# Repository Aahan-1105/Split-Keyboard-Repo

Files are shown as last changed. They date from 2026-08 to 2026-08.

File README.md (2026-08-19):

# Venturi - 48 Key Split Keyboard
*Code name: Model 901*

My first PCBs, first personal electronics project, and much more. This has been a lot of firsts so please excuse mistakes. Key inspiration is also mentioned below.

Steal from the best, invent the rest

## FIRMWARE in THIS REPO

## Overview
The Venturi (aka model 901, venturi48) is a 48-key split, ergonomic keyboard. I can use lots of descriptors, but you can find that in the features section. 

## Contents
- All the KiCad files, including schematics and PCB
- All CAD Files including an assembly including all the components on the left side and cases for both
- ZMK firmware for Venturi
- Production files as used for production

## Images

### CAD Render
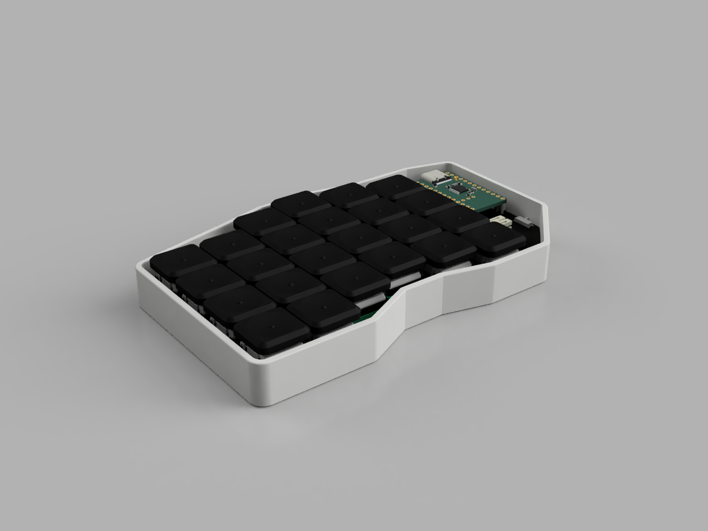
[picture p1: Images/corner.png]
Corner Render


### Schematic (Left)
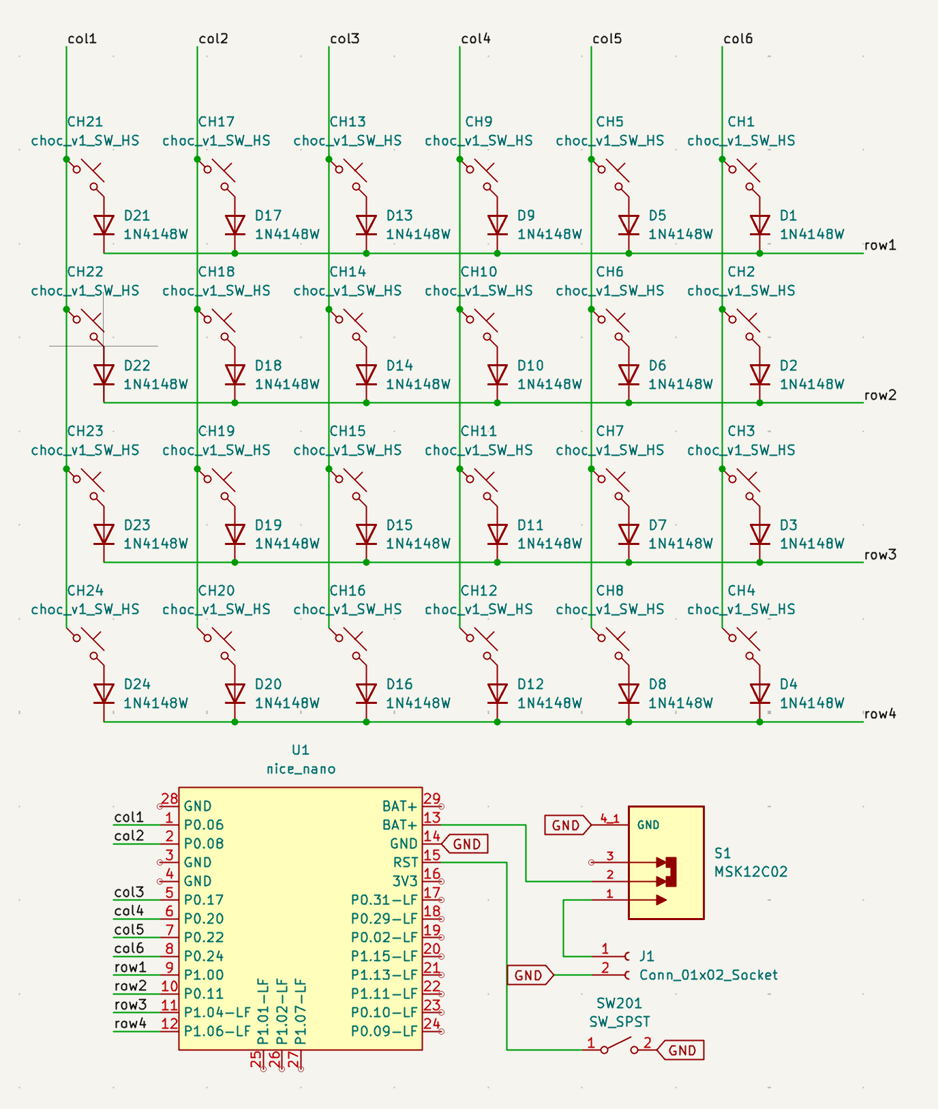
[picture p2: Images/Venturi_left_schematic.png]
Left Schematic


### PCB (Panelized)
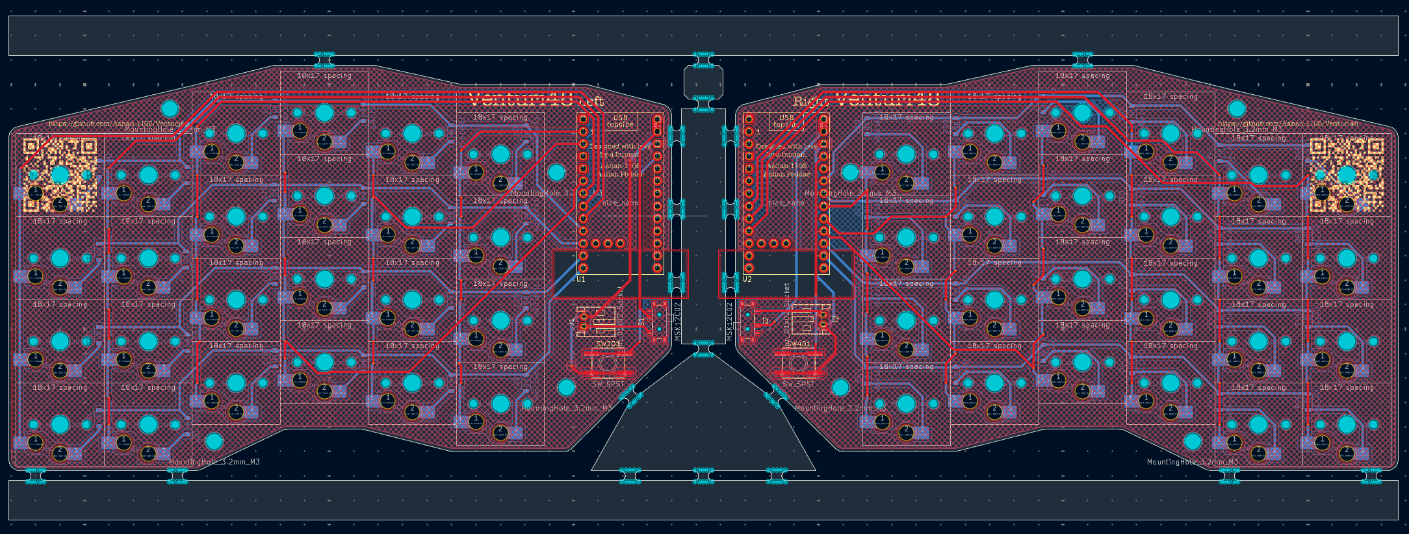
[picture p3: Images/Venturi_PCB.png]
Panelized PCB


## To-Do
- Triple-check that PCBs are good and needed components are accounted for
- PURCHASE
- Assemble and test!

## Features
- **48 Keys**  - All laptop keys within 2 layers, with additional layers for extra functionality. 
- **Wireless** - One less cable to worry about! 2x 110 maH LiPO Batteries, 2+ week battery life (estimated). Seamless multi-device operation.
- **Column Stagger** - Some mild colstag makes it more comfy to type on by better suting the different finger lengths
- **Keyboard Continuity** - Closer layout to a Macbook or general keyboard than most ergo KBs, so that you're not mad at all other keyboards while using this
- **Low Profile**  - Thinner = Better? More portable and less of an upward angle on the wrists, no need for a wrist rest 
- **Portable** - Easy on the go typing via a 3d print to easily carry it without risking damage in a backpack
- **Hot-Swappable** - Changed your mind on those clicky switches? Or maybe you're looking for a change of pace? The Venturi has you covered with hotswap switches!
- **Magsafe** - Not to wirelessly charge or to attach to the back of your phone, but for convenient tenting or to check if that coin is magnetic or not (it wasn't)

## BOM (For Hackclub Stardance Purposes)
|Purchase Status|Part |Qty|Price/per (CAD)|Total |Link |Shipping/Tax|Notes |
|---|---|---|---|---|---|---|---|
| |NRF52840 Dev Board |2  |$3.95 |$7.90 |https://a.aliexpress.com/_mrUhUVZ| |MC |
| |MSK12C02 (20 pack) |1  |$3.85 |$3.85 |https://a.aliexpress.com/_mLPJnJ1| |Power Switch |
| |JST PH 2.0 Bent Plug (100 pack)|1  |$2.61 |$2.61 |https://a.aliexpress.com/_m0dvH4j| |Battery Connector |
| |1N4148W Diode (100 pack) |1  |$2.07 |$2.07 |https://a.aliexpress.com/_mNCQ5SX| |Diodes |
| |Choc Hotswap Socket (70 pack)  |1  |$10.48 |$10.48|https://a.aliexpress.com/_mq1DDpN| |Hotswap Socket |
| |2.54mm socket (10 pack) |1  |$2.64 |$2.64 |https://a.aliexpress.com/_mtOu6HZ| |Sockets for MC |
| |KailH Choc Pro Red |1  |$32.26 |$32.26|https://a.aliexpress.com/_mKtAtkx| |Switch |
| |301230 Battery JST |2  |$5.19 |$10.38|https://a.aliexpress.com/_mt5WUH1|6.18 |Battery |
| |JLCPCB PCB |1  |$17.73 |$17.73| |12.37 |PCB (no link available)  |
| |FNIRSI HS-02A Basic |1  |$39.44 |$39.44|https://a.aliexpress.com/_mKQRvMj| |Soldering Iron |
| |Magsafe Ring (6) |1  |$7.51 |$7.51 |https://a.aliexpress.com/_mtm6duj| |Magsafe Ring for Mounting|
| |20g Lead-free solder |1  |$5.29 |$5.29 |https://a.aliexpress.com/_mKjygpD| |Soldering |
| |Flux Pen 10mL |1  |$4.98 |$4.98 |https://a.aliexpress.com/_mKjygpD| |Flux for soldering |
| | | | |$0.00 | | | |
| | | | |$0.00 | | | |
| |TOTAL (CAD) | |$165.69 |$0.00 | | | |
| |TOTAL (USD) | |$119.30 |$0.00 | | | |

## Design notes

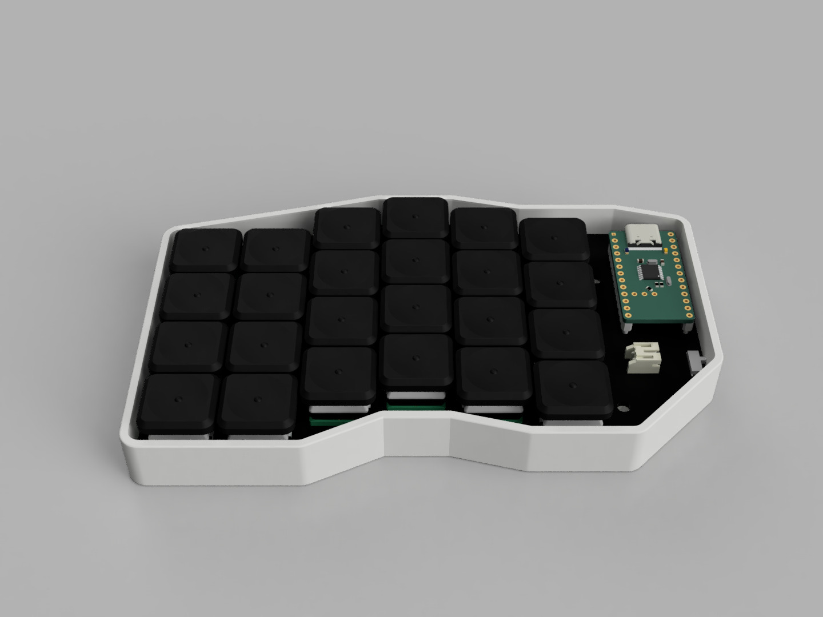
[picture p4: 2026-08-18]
Images/front.png

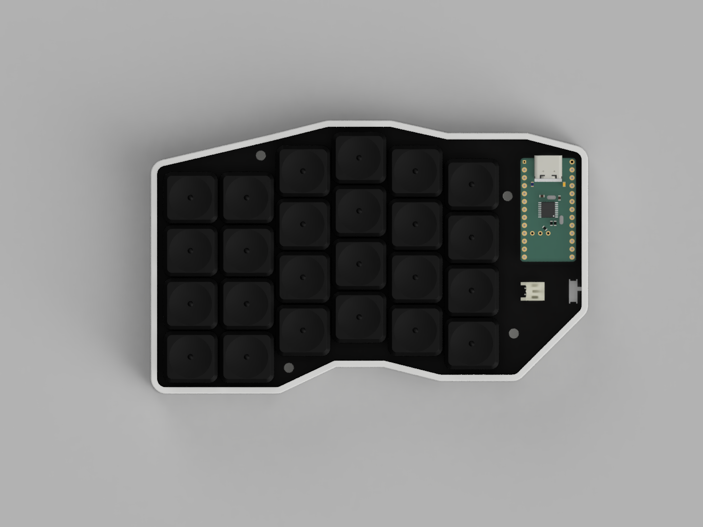
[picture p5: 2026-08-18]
Images/top.png

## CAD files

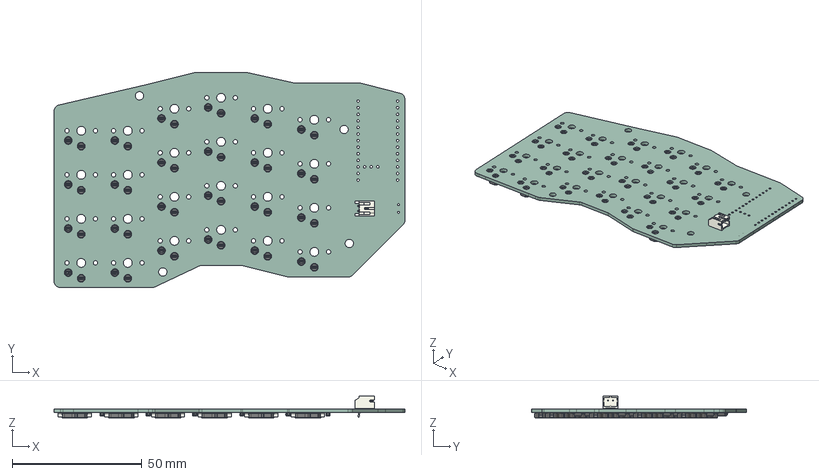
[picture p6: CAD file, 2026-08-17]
CAD/External STEP Files/Left_Half.step
135.5 x 83.0 x 8.49 mm
JST_S2B_PH_K
pin x 48
socket x 24
D_SOD-123 x 24
Left_Half_PCB-unsaved-export-nb2ApT_PCB

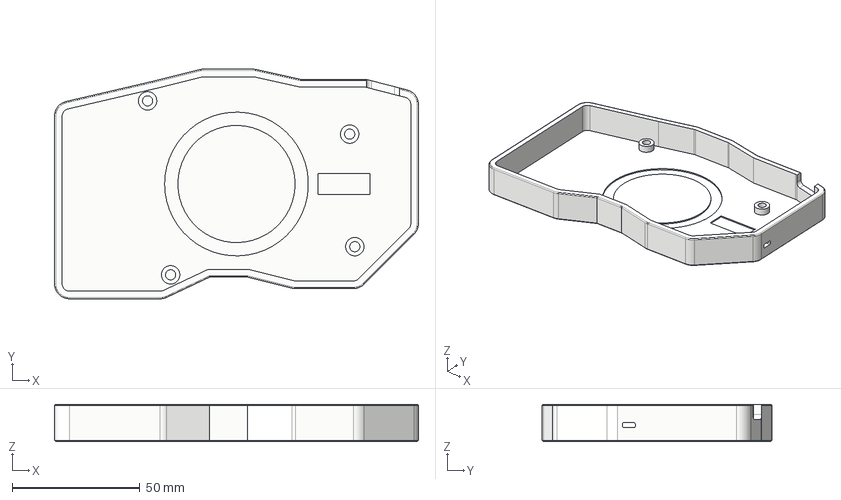
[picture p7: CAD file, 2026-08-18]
CAD/Venturi Left Half Case.step
142.3 x 89.8 x 14.6 mm

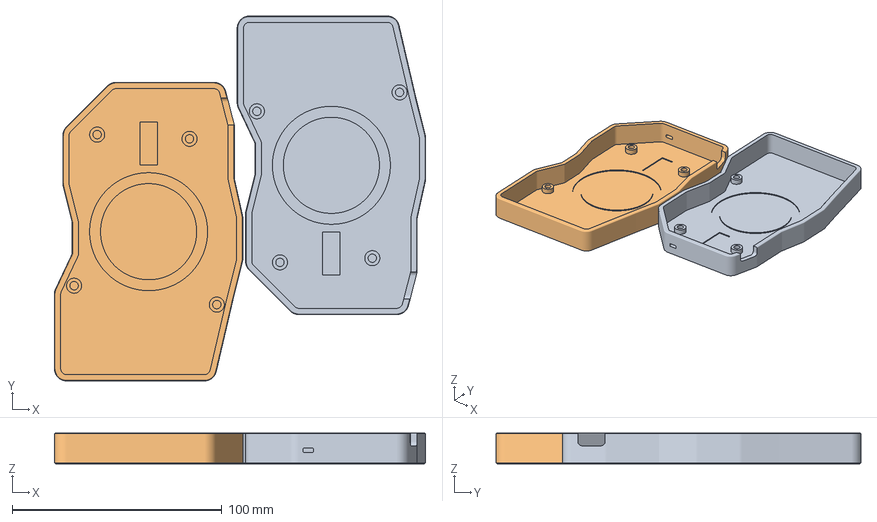
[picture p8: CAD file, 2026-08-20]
Production/Venturi48-case.3mf
176.9 x 173.9 x 14.6 mm
Left Half Case x 2

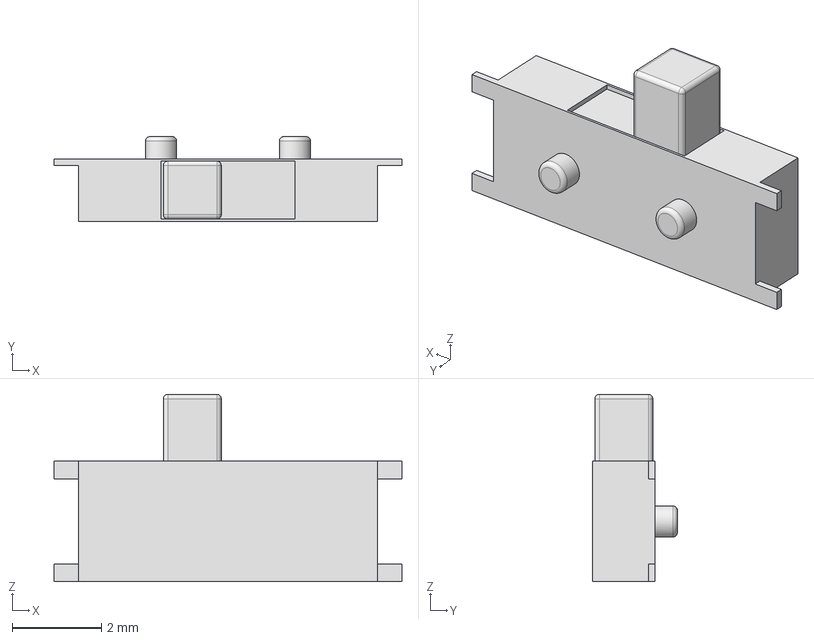
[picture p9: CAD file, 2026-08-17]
CAD/External STEP Files/msk12c02.step
7.80 x 1.90 x 4.20 mm

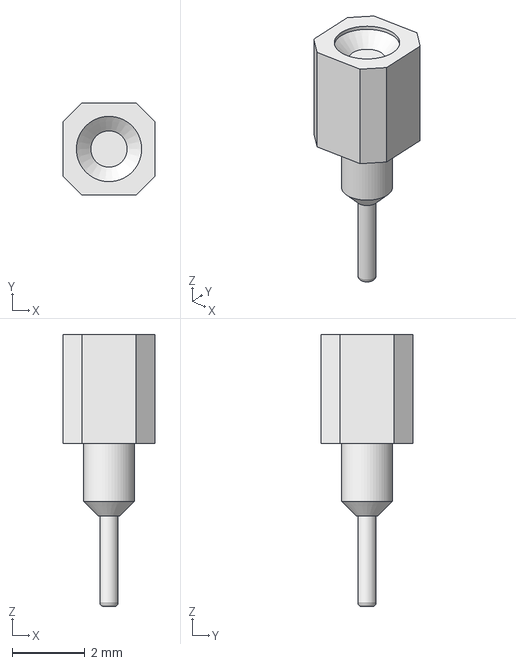
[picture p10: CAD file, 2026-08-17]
CAD/External STEP Files/Header-Female-round.step
2.54 x 2.54 x 7.50 mm

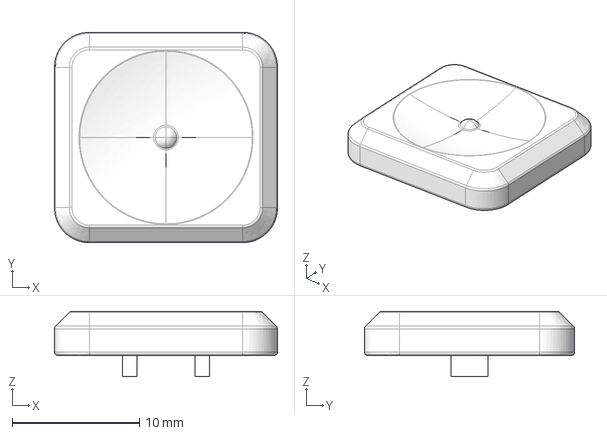
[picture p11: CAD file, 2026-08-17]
CAD/External STEP Files/kea-choc-v1-choc-spaced-homing-keycap-1u.stp
17.6 x 16.6 x 5.14 mm

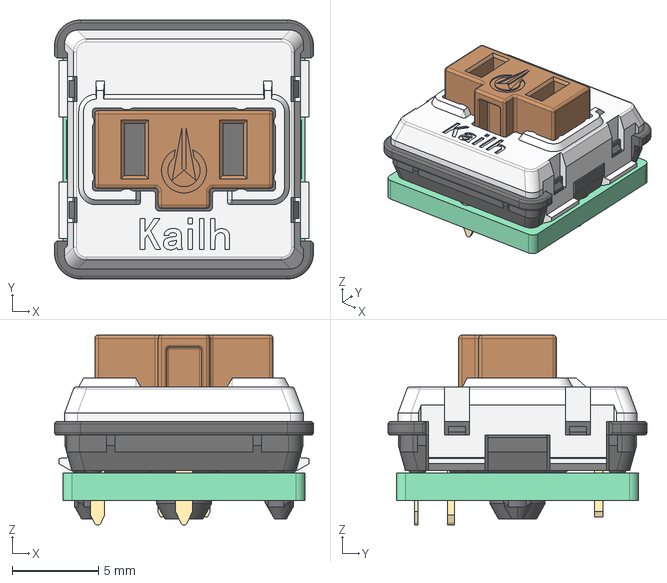
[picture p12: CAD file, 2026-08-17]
CAD/External STEP Files/Kailh Choc Low Profile Switch.step
15.0 x 15.0 x 11.0 mm

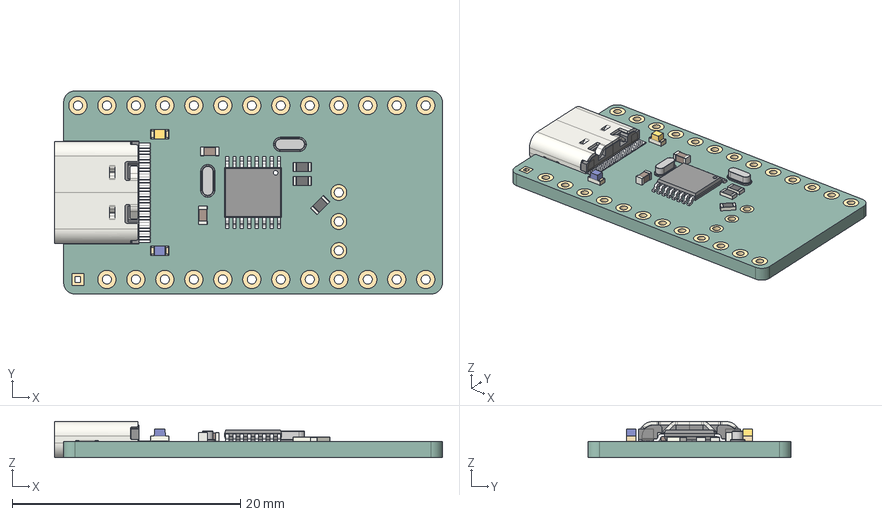
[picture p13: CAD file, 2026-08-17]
CAD/External STEP Files/nice!nano v2.step
34.0 x 17.8 x 3.16 mm
nice!nano v1.0_1
USB_C_Receptacle_16P_TopMnt_Horizontal_GCT_USB4105-xx-A
USB_C_Receptacle_16P_TopMnt_Horizontal_GCT_USB4105-xx-A001
USB_C_Receptacle_16P_TopMnt_Horizontal_GCT_USB4105-xx-A002
USB_C_Receptacle_16P_TopMnt_Horizontal_GCT_USB4105-xx-A003
USB_C_Receptacle_16P_TopMnt_Horizontal_GCT_USB4105-xx-A004
USB_C_Receptacle_16P_TopMnt_Horizontal_GCT_USB4105-xx-A005
USB_C_Receptacle_16P_TopMnt_Horizontal_GCT_USB4105-xx-A006
USB_C_Receptacle_16P_TopMnt_Horizontal_GCT_USB4105-xx-A007
USB_C_Receptacle_16P_TopMnt_Horizontal_GCT_USB4105-xx-A008
USB_C_Receptacle_16P_TopMnt_Horizontal_GCT_USB4105-xx-A009
USB_C_Receptacle_16P_TopMnt_Horizontal_GCT_USB4105-xx-A010
USB_C_Receptacle_16P_TopMnt_Horizontal_GCT_USB4105-xx-A011
USB_C_Receptacle_16P_TopMnt_Horizontal_GCT_USB4105-xx-A012
USB_C_Receptacle_16P_TopMnt_Horizontal_GCT_USB4105-xx-A013
USB_C_Receptacle_16P_TopMnt_Horizontal_GCT_USB4105-xx-A014
USB_C_Receptacle_16P_TopMnt_Horizontal_GCT_USB4105-xx-A015
USB_C_Receptacle_16P_TopMnt_Horizontal_GCT_USB4105-xx-A016
USB_C_Receptacle_16P_TopMnt_Horizontal_GCT_USB4105-xx-A017
USB_C_Receptacle_16P_TopMnt_Horizontal_GCT_USB4105-xx-A018
USB_C_Receptacle_16P_TopMnt_Horizontal_GCT_USB4105-xx-A019
USB_C_Receptacle_16P_TopMnt_Horizontal_GCT_USB4105-xx-A020
USB_C_Receptacle_16P_TopMnt_Horizontal_GCT_USB4105-xx-A021
USB_C_Receptacle_16P_TopMnt_Horizontal_GCT_USB4105-xx-A022
USB_C_Receptacle_16P_TopMnt_Horizontal_GCT_USB4105-xx-A023
USB_C_Receptacle_16P_TopMnt_Horizontal_GCT_USB4105-xx-A024
USB_C_Receptacle_16P_TopMnt_Horizontal_GCT_USB4105-xx-A025
USB_C_Receptacle_16P_TopMnt_Horizontal_GCT_USB4105-xx-A026
USB_C_Receptacle_16P_TopMnt_Horizontal_GCT_USB4105-xx-A027
USB_C_Receptacle_16P_TopMnt_Horizontal_GCT_USB4105-xx-A028
USB_C_Receptacle_16P_TopMnt_Horizontal_GCT_USB4105-xx-A029
USB_C_Receptacle_16P_TopMnt_Horizontal_GCT_USB4105-xx-A030
USB_C_Receptacle_16P_TopMnt_Horizontal_GCT_USB4105-xx-A031
USB_C_Receptacle_16P_TopMnt_Horizontal_GCT_USB4105-xx-A032
USB_C_Receptacle_16P_TopMnt_Horizontal_GCT_USB4105-xx-A033
USB_C_Receptacle_16P_TopMnt_Horizontal_GCT_USB4105-xx-A034
USB_C_Receptacle_16P_TopMnt_Horizontal_GCT_USB4105-xx-A035
Pin9
Pin10
Pin12
Pin11
Pin13
Pin14
Pin15
Pin16
Pin8
Pin7
Pin6
Pin5
Pin4
Pin3
Pin2
Pin1
LED_0603_1608Metric_ON
C_0603_1608Metric x 2
LED_0603_1608Metric_ON_1
Crystal Oscillator x 2
R_0603_1608Metric x 4

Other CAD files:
PCB and KiCad/.step
CAD/External STEP Files/msk12c02.ipt

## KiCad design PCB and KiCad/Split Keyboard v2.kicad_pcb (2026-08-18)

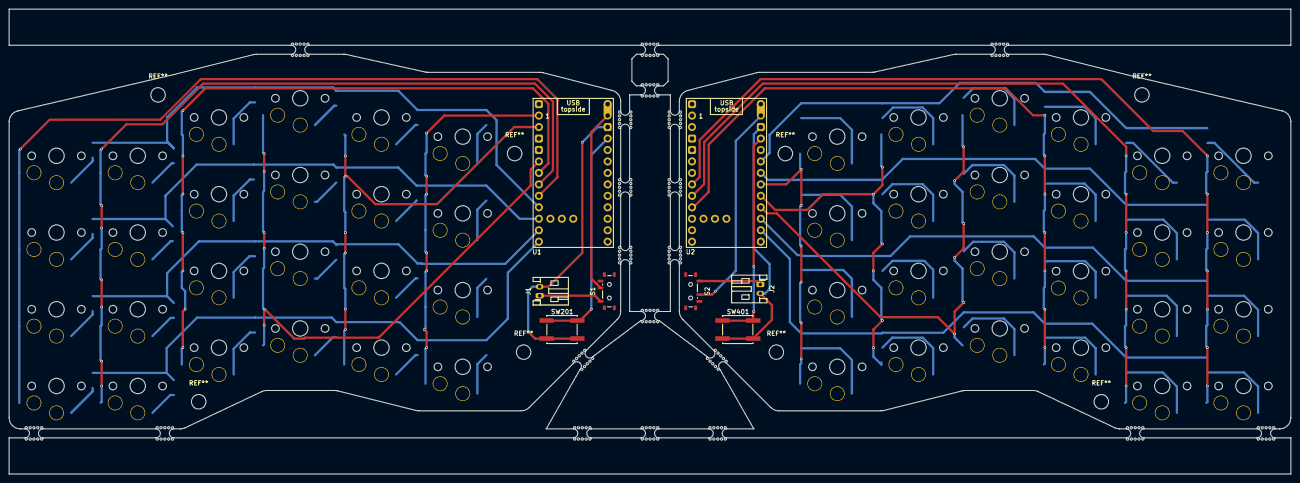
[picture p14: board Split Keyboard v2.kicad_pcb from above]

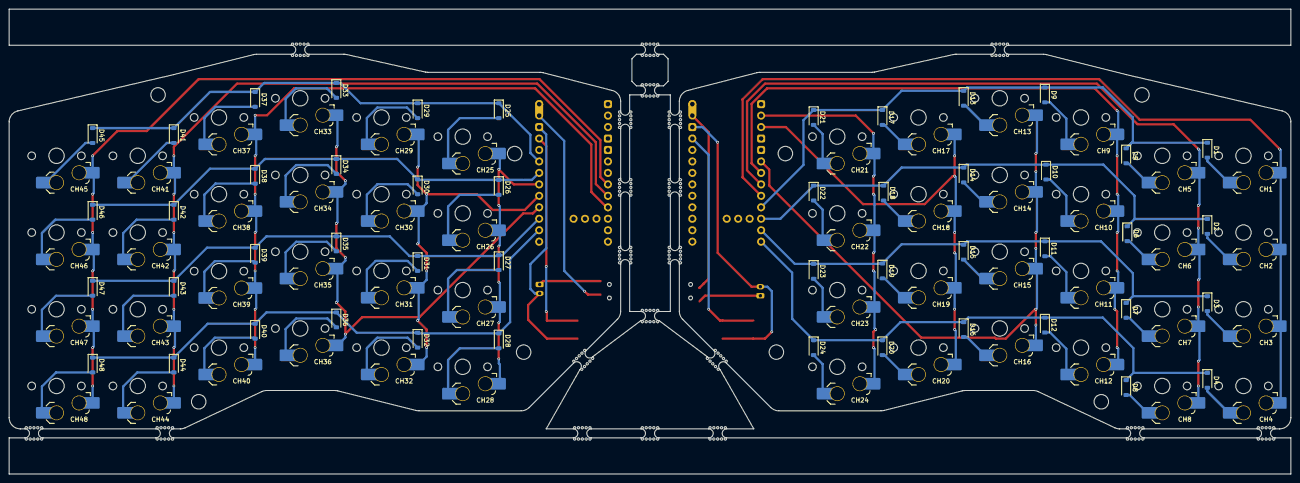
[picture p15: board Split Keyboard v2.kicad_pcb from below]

Board: 2 copper layers, 284.0 x 103.0 mm, 104 parts (96 on the bottom side), 76 nets.

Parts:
CH1, CH2, CH3, CH4, CH5, CH6, CH7, CH8, CH9, CH10, CH11, CH12, CH13, CH14, CH15, CH16, CH17, CH18, CH19, CH20, CH21, CH22, CH23, CH24, CH25, CH26, CH27, CH28, CH29, CH30, CH31, CH32, CH33, CH34, CH35, CH36, CH37, CH38, CH39, CH40, CH41, CH42, CH43, CH44, CH45, CH46, CH47, CH48: choc_v1_SW_HS; SW_choc_v1_HS_CPG135001S30_1u
D1, D2, D3, D4, D5, D6, D7, D8, D9, D10, D11, D12, D13, D14, D15, D16, D17, D18, D19, D20, D21, D22, D23, D24, D25, D26, D27, D28, D29, D30, D31, D32, D33, D34, D35, D36, D37, D38, D39, D40, D41, D42, D43, D44, D45, D46, D47, D48: 1N4148W; D_SOD-123
J1, J2: Conn_01x02_Socket; JST_PH_S2B-PH-K_1x02_P2.00mm_Horizontal
S1, S2: MSK12C02; SW_SPDT_Shouhan_MSK12C02
SW201, SW401: SW_SPST; SW_SPST_EVQQ2
U1, U2: nice_nano; nice_nano_AH_USBup

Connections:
/Left_Half/col1: CH21.1, CH22.1, CH23.1, CH24.1, U1.1 (P0.06)
/Left_Half/col2: CH17.1, CH18.1, CH19.1, CH20.1, U1.2 (P0.08)
/Left_Half/col3: CH13.1, CH14.1, CH15.1, CH16.1, U1.5 (P0.17)
/Left_Half/col4: CH9.1, CH10.1, CH11.1, CH12.1, U1.6 (P0.20)
/Left_Half/col5: CH5.1, CH6.1, CH7.1, CH8.1, U1.7 (P0.22)
/Left_Half/col6: CH1.1, CH2.1, CH3.1, CH4.1, U1.8 (P0.24)
/Left_Half/row1: D1.1 (K), D5.1 (K), D9.1 (K), D13.1 (K), D17.1 (K), D21.1 (K), U1.9 (P1.00)
/Left_Half/row2: D2.1 (K), D6.1 (K), D10.1 (K), D14.1 (K), D18.1 (K), D22.1 (K), U1.10 (P0.11)
/Left_Half/row3: D3.1 (K), D7.1 (K), D11.1 (K), D15.1 (K), D19.1 (K), D23.1 (K), U1.11 (P1.04-LF)
/Left_Half/row4: D4.1 (K), D8.1 (K), D12.1 (K), D16.1 (K), D20.1 (K), D24.1 (K), U1.12 (P1.06-LF)
/Right_Half/col1: CH25.1, CH26.1, CH27.1, CH28.1, U2.19 (P0.02-LF)
/Right_Half/col2: CH29.1, CH30.1, CH31.1, CH32.1, U2.20 (P1.15-LF)
/Right_Half/col3: CH33.1, CH34.1, CH35.1, CH36.1, U2.21 (P1.13-LF)
/Right_Half/col4: CH37.1, CH38.1, CH39.1, CH40.1, U2.9 (P1.00)
/Right_Half/col5: CH41.1, CH42.1, CH43.1, CH44.1, U2.8 (P0.24)
/Right_Half/col6: CH45.1, CH46.1, CH47.1, CH48.1, U2.7 (P0.22)
/Right_Half/row1: D25.1 (K), D29.1 (K), D33.1 (K), D37.1 (K), D41.1 (K), D45.1 (K), U2.17 (P0.31-LF)
/Right_Half/row2: D26.1 (K), D30.1 (K), D34.1 (K), D38.1 (K), D42.1 (K), D46.1 (K), U2.18 (P0.29-LF)
/Right_Half/row3: D27.1 (K), D31.1 (K), D35.1 (K), D39.1 (K), D43.1 (K), D47.1 (K), U2.22 (P1.11-LF)
/Right_Half/row4: D28.1 (K), D32.1 (K), D36.1 (K), D40.1 (K), D44.1 (K), D48.1 (K), U2.23 (P0.10-LF)
unnamed: CH1.2, D1.2 (A)
unnamed: CH2.2, D2.2 (A)
unnamed: CH3.2, D3.2 (A)
unnamed: CH4.2, D4.2 (A)
unnamed: CH5.2, D5.2 (A)
unnamed: CH6.2, D6.2 (A)
unnamed: CH7.2, D7.2 (A)
unnamed: CH8.2, D8.2 (A)
unnamed: CH9.2, D9.2 (A)
unnamed: CH10.2, D10.2 (A)
unnamed: CH11.2, D11.2 (A)
unnamed: CH12.2, D12.2 (A)
unnamed: CH13.2, D13.2 (A)
unnamed: CH14.2, D14.2 (A)
unnamed: CH15.2, D15.2 (A)
unnamed: CH16.2, D16.2 (A)
unnamed: CH17.2, D17.2 (A)
unnamed: CH18.2, D18.2 (A)
unnamed: CH19.2, D19.2 (A)
unnamed: CH20.2, D20.2 (A)
unnamed: CH21.2, D21.2 (A)
unnamed: CH22.2, D22.2 (A)
unnamed: CH23.2, D23.2 (A)
unnamed: CH24.2, D24.2 (A)
unnamed: CH25.2, D25.2 (A)
unnamed: CH26.2, D26.2 (A)
unnamed: CH27.2, D27.2 (A)
unnamed: CH28.2, D28.2 (A)
unnamed: CH29.2, D29.2 (A)
unnamed: CH30.2, D30.2 (A)
unnamed: CH31.2, D31.2 (A)
unnamed: CH32.2, D32.2 (A)
unnamed: CH33.2, D33.2 (A)
unnamed: CH34.2, D34.2 (A)
unnamed: CH35.2, D35.2 (A)
unnamed: CH36.2, D36.2 (A)
unnamed: CH37.2, D37.2 (A)
unnamed: CH38.2, D38.2 (A)
unnamed: CH39.2, D39.2 (A)
unnamed: CH40.2, D40.2 (A)
unnamed: CH41.2, D41.2 (A)
unnamed: CH42.2, D42.2 (A)
unnamed: CH43.2, D43.2 (A)
unnamed: CH44.2, D44.2 (A)
unnamed: CH45.2, D45.2 (A)
unnamed: CH46.2, D46.2 (A)
unnamed: CH47.2, D47.2 (A)
unnamed: CH48.2, D48.2 (A)
unnamed: J1.1, S1.1
unnamed: J1.2, SW201.2 (B), U1.14 (GND)
unnamed: J2.1, S2.1
unnamed: J2.2, SW401.2 (B), U2.14 (GND)
unnamed: S1.2, U1.13 (BAT+)
unnamed: S2.2, U2.13 (BAT+)
unnamed: SW201.1 (A), U1.15 (RST)
unnamed: SW401.1 (A), U2.15 (RST)

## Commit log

2026-08-17 Adding current work
2026-08-17 Removed some extra stuff :)
    [Left_Half.step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]
2026-08-18 Added Images and update readme
    [Split Keyboard v2.kicad_pcb]
2026-08-18 Added BOM csv file
    [Venturi BOM.csv]
2026-08-18 Update README.md
    Includes BOM for Stardance
2026-08-18 Added info on silkscreen
2026-08-18 Case and Assembly Step Added
    [Venturi Left Half Case.step]
2026-08-18 updated silkscreen
2026-08-19 Fillzone changes and updated gerber
    [left_half.kicad_sch, right_half.kicad_sch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]
2026-08-19 Improved Production Directory
    [Venturi48-case.3mf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]
2026-08-20 Updated PCB
    [Split Keyboard v2-B_Mask.gbr, Split Keyboard v2-B_Silkscreen.gbr, Split Keyboard v2-Edge_Cuts.gbr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]
2026-08-20 Fixed PCB Production Files
    [Split Keyboard v2-B_Mask.gbr, Split Keyboard v2-B_Silkscreen.gbr, Split Keyboard v2-Edge_Cuts.gbr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]
